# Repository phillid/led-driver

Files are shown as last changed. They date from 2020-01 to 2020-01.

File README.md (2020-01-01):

# LM3409HV LED Driver Boards

These are Kicad files for a 450 mA constant current LED driver built around
the LM3409HV, based mostly on the sample schematic in the TI datasheet.

It is designed for 48 volts in and 450 mA CC out, to drive Cree's 16.7 watt
LEDs with Vf of 37 volts.

The PCB measures about 34x32 mm.

More concrete and interesting details to follow as I send the boards to
manufacture, build them up, find the glaring errors I'm too blind to see,
and let the magic smoke out of some components 😜

## Version history

* **v1.1** (BOM change)
	This version changes R2 so that the UVLO is programmed for 43 V turn-on.
	This is to avoid over-driving the LEDs when the power supply voltage is
	low enough to make the driver incapable of reaching the peak LED current,
	which otherwise results in a raising of the average current.
* **v1**
	First, and prototype, revision. Started design in 2017 and finally got
	around to getting boards manufactured in May 2019 after taking a long
	break from the project. These are the first boards to be manufactured.

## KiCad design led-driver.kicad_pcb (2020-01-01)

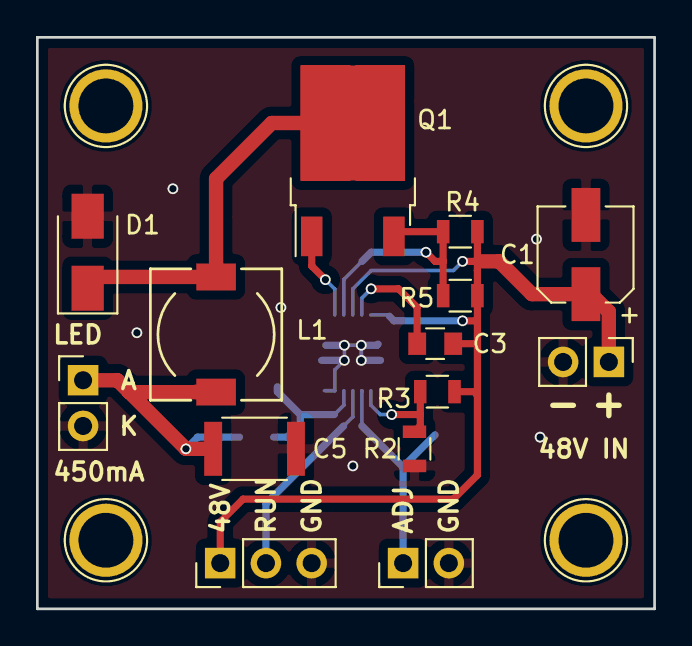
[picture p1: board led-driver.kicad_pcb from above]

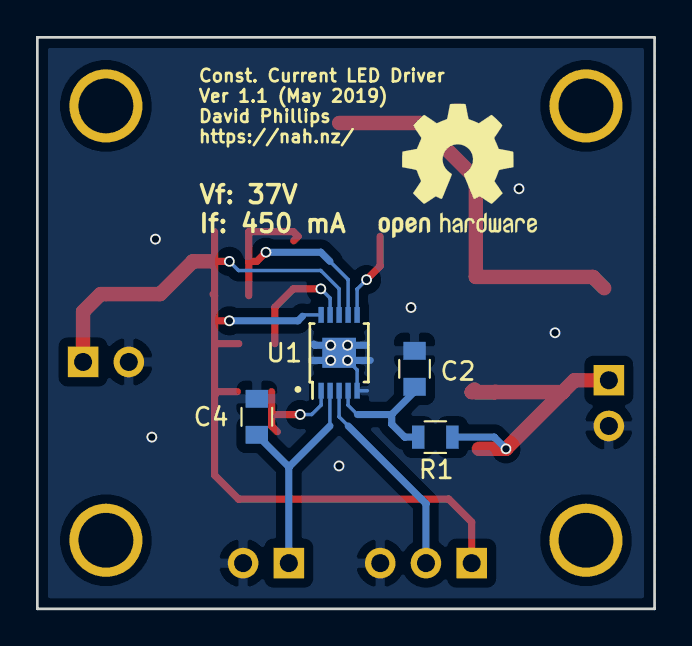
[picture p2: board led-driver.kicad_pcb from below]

Board: 2 copper layers, 34.3 x 31.7 mm, 18 parts (4 on the bottom side), 11 nets.

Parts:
C1: 3.3µF; CP_Elec_5x5.3
C2: 1nF; C_0805
C3: 1µF; C_0805
C4: 100nF; C_0805
C5: 470nF; C_1812
D1: B1100-13-F; D_SMA
J1: 48VDC IN; Pin_Header_Straight_1x02_Pitch2.54mm
J2: ENABLE; Pin_Header_Straight_1x03_Pitch2.54mm
J3: ADJ; Pin_Header_Straight_1x02_Pitch2.54mm
J4: LED; Pin_Header_Straight_1x02_Pitch2.54mm
L1: 33µH; Choke_SMD_7.3x7.3_H3.5
Q1: ZXMP7A17KTC; TO-252-2
R1: 11kΩ; R_0805
R2: 1.47kΩ; R_0805
R3: 49.9kΩ; R_0805
R4: 0.374Ω; R_0805
R5: Spare; R_0805
U1: LM3409HV; MSOP-10-1EP_3x3mm_Pitch0.5mm

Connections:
GND: C1.2, C2.2, C4.1, C5.2, D1.2, J1.2, J2.3, J3.2, J4.2, R2.2, U1.5, U1.11
unnamed: C2.1, R1.2, U1.4
unnamed: C3.2, U1.9
unnamed: C4.2, J3.1, U1.2
unnamed: C5.1, J4.1, L1.2, R1.1
unnamed: D1.1, L1.1, Q1.2
unnamed: J2.2, U1.3
unnamed: Q1.1, U1.6
unnamed: Q1.3, R4.2, R5.2, U1.7
unnamed: R2.1, R3.2, U1.1
VCC: C1.1, C3.1, J1.1, J2.1, R3.1, R4.1, R5.1, U1.8, U1.10

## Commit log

2017-09-10 Add PCB prototype, schematic, gitignore
    [led-driver.kicad_pcb, led-driver.sch]
2019-05-31 Rescue symbols, minor revisions to PCB
    This commits previous work that took place sporadically between the last
    commit a year and a half ago, and now.
    [led-driver.kicad_pcb, led-driver.sch]
2019-05-31 Reduce clearances, margin on MSOP footprint
    Reduction of the soldermask margin allows soldermask to be placed between the
    landing pads for the leads, which should aid soldering. Reduction of the
    pad clearance should stop DRC from complaining about nets too close together.
    [led-driver.kicad_pcb]
2019-05-31 Add PWR_FLAGs to power input
    This quells warnings about connected-but-not-driven nets for GND and VCC
    [led-driver.sch]
2020-01-01 Increase UVLO turn-on to 43 V
    The initial design assumed that the UVLO was a feature of the LM3409 not needed
    by this board. It was set at the datasheet values of 10.1 V turn-on with 1.1 V
    of hysteresis. However, during testing, I have found that the supply will sink
    a maximum of around 600 mA into the load when operated into dropout. The LM3409
    datasheet confirms that this is expected behaviour. Since the supply is
    designed for LEDs modules with a forward voltage of 37 V, this patch changes
    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
    [led-driver.kicad_pcb, led-driver.sch]
2020-01-01 Bump to Version 1.1
    [led-driver.sch]
2020-01-01 Fix up symbols
    [led-driver.sch]
